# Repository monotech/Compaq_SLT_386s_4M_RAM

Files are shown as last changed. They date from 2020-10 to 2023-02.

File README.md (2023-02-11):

# Compaq SLT 386s/20 4MiB RAM Module

Can be used alongside original modules.

The DRAM chips are obsolete and need to be purchased from the grey market.

The example part numbers below are just examples. There are many compatible chips from different brands with quite different part numbers. Compare datasheets.

Original modules used 80ns chips, so acquire chips that are 80ns or faster. I used 60ns just fine. Beware of fake/bad parts.

It's best to order with ENIG surface finish rather than HASL. If you'll be replugging it over a hundred times, selective 30u" hard-gold plating is recommended.

## Bill of materials
Designator|Part
---|---
U1-2,U4-5,U7-8,U10-11|1M*4 DRAM SOJ-20(26-size) or TSOP-II such as HY514400ALJ-60
U3,U6,U9,U12|1M*1 DRAM SOJ-20(26-size) or TSOP-II such as HY531000ALJ-50
U13-14|74AHC541 TSSOP-20
C1|10uF 0805
C2-9|100nF 0603
R1-14|33 ohm 0603

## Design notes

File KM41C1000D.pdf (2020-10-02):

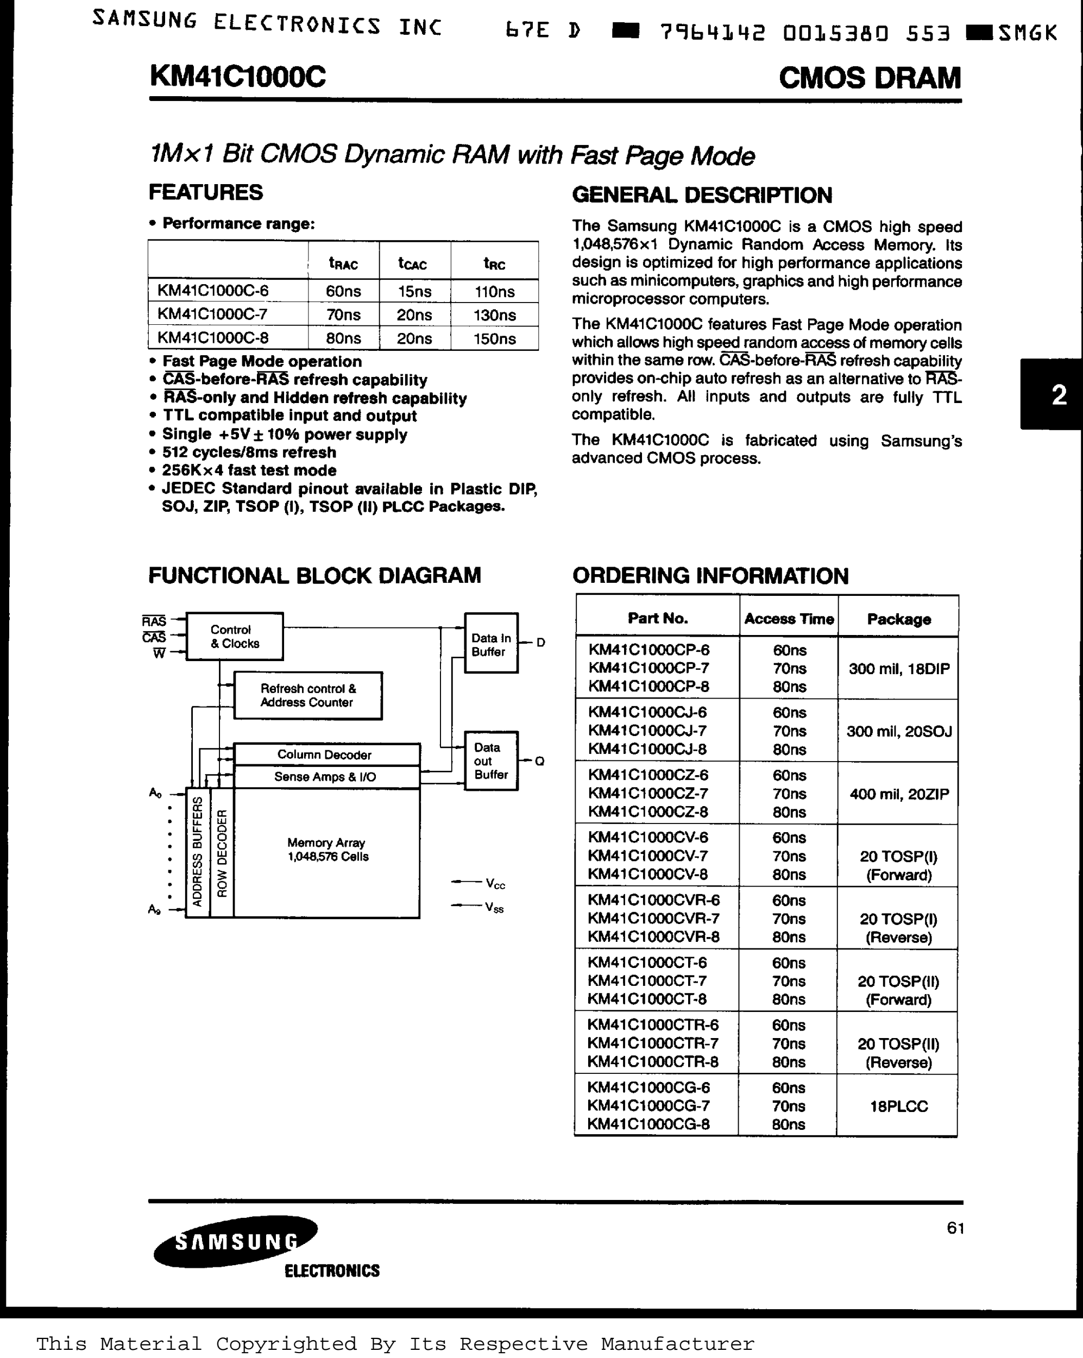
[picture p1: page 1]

This Material Copyrighted By Its Respective Manufacturer

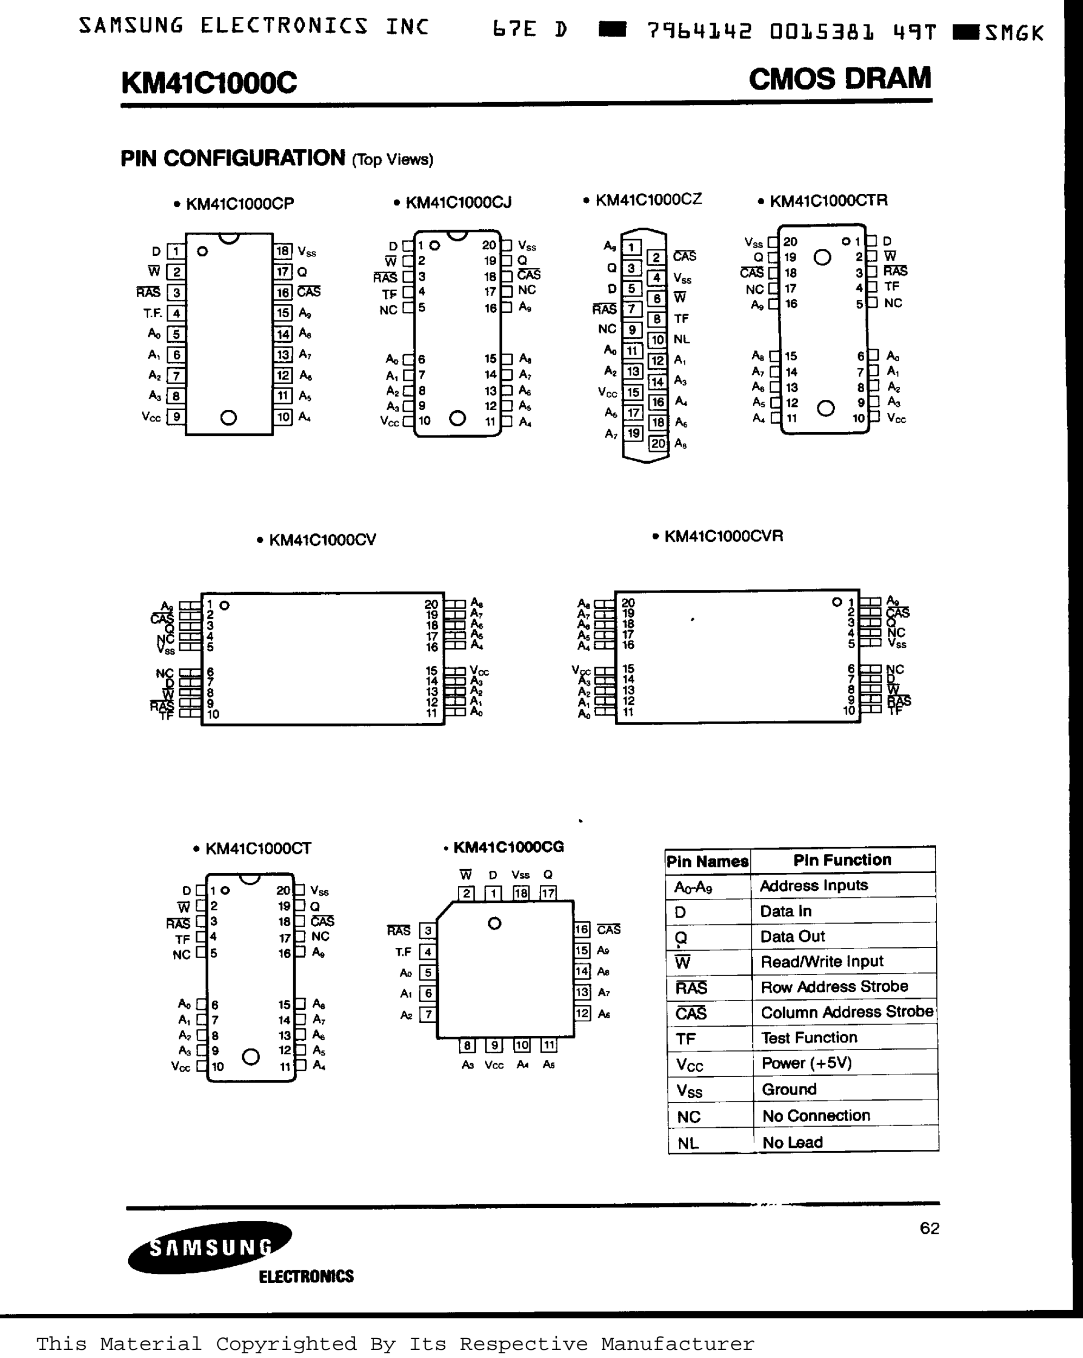
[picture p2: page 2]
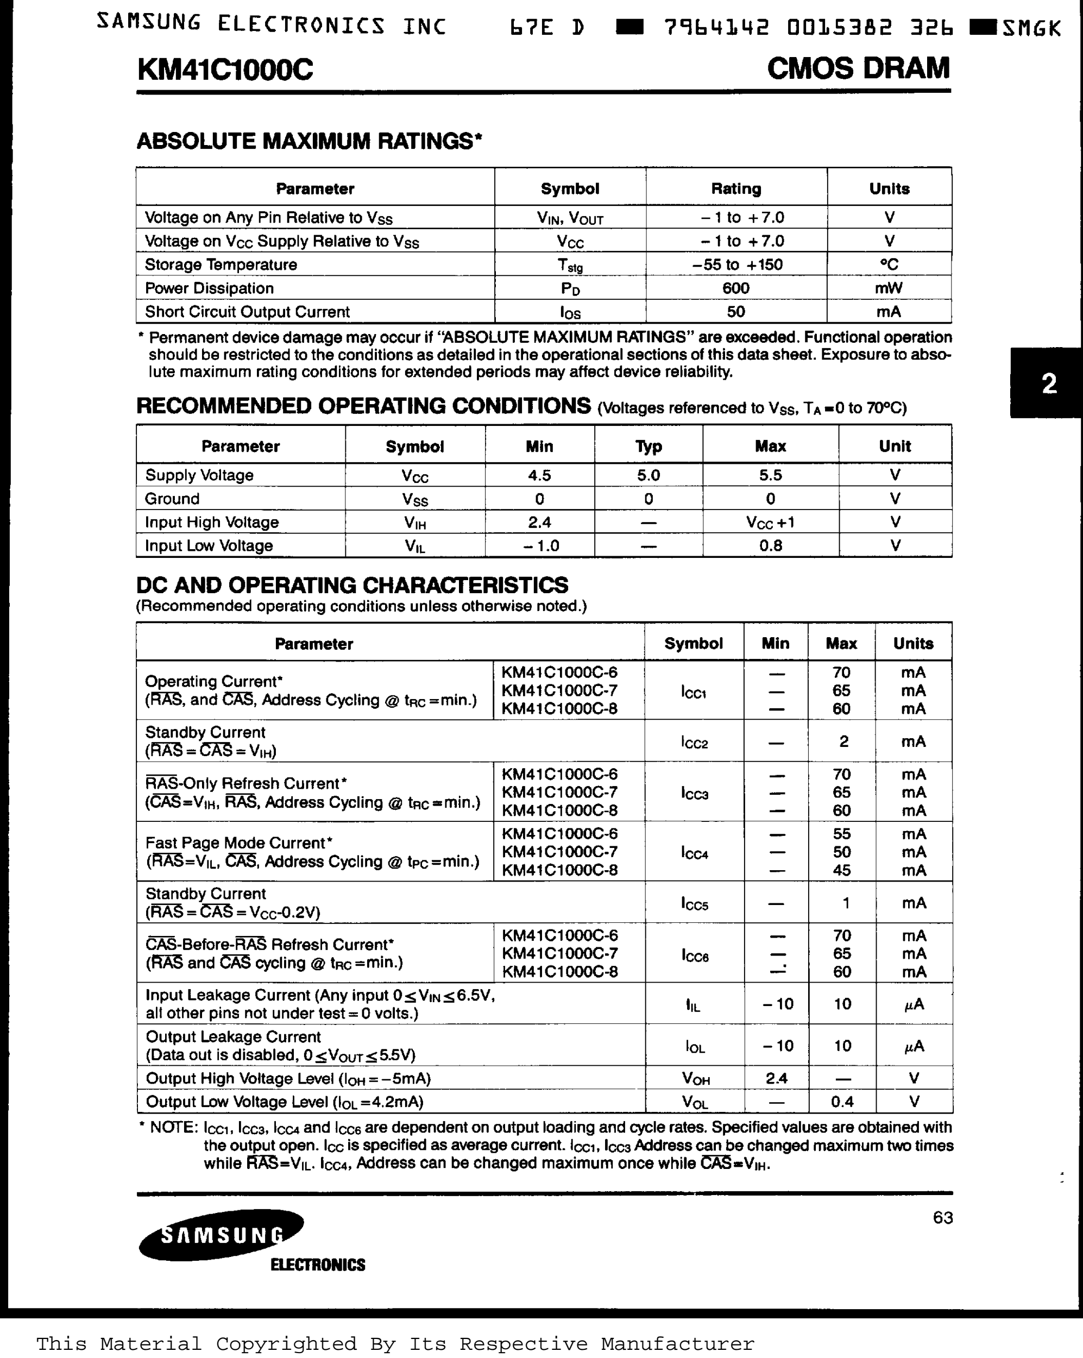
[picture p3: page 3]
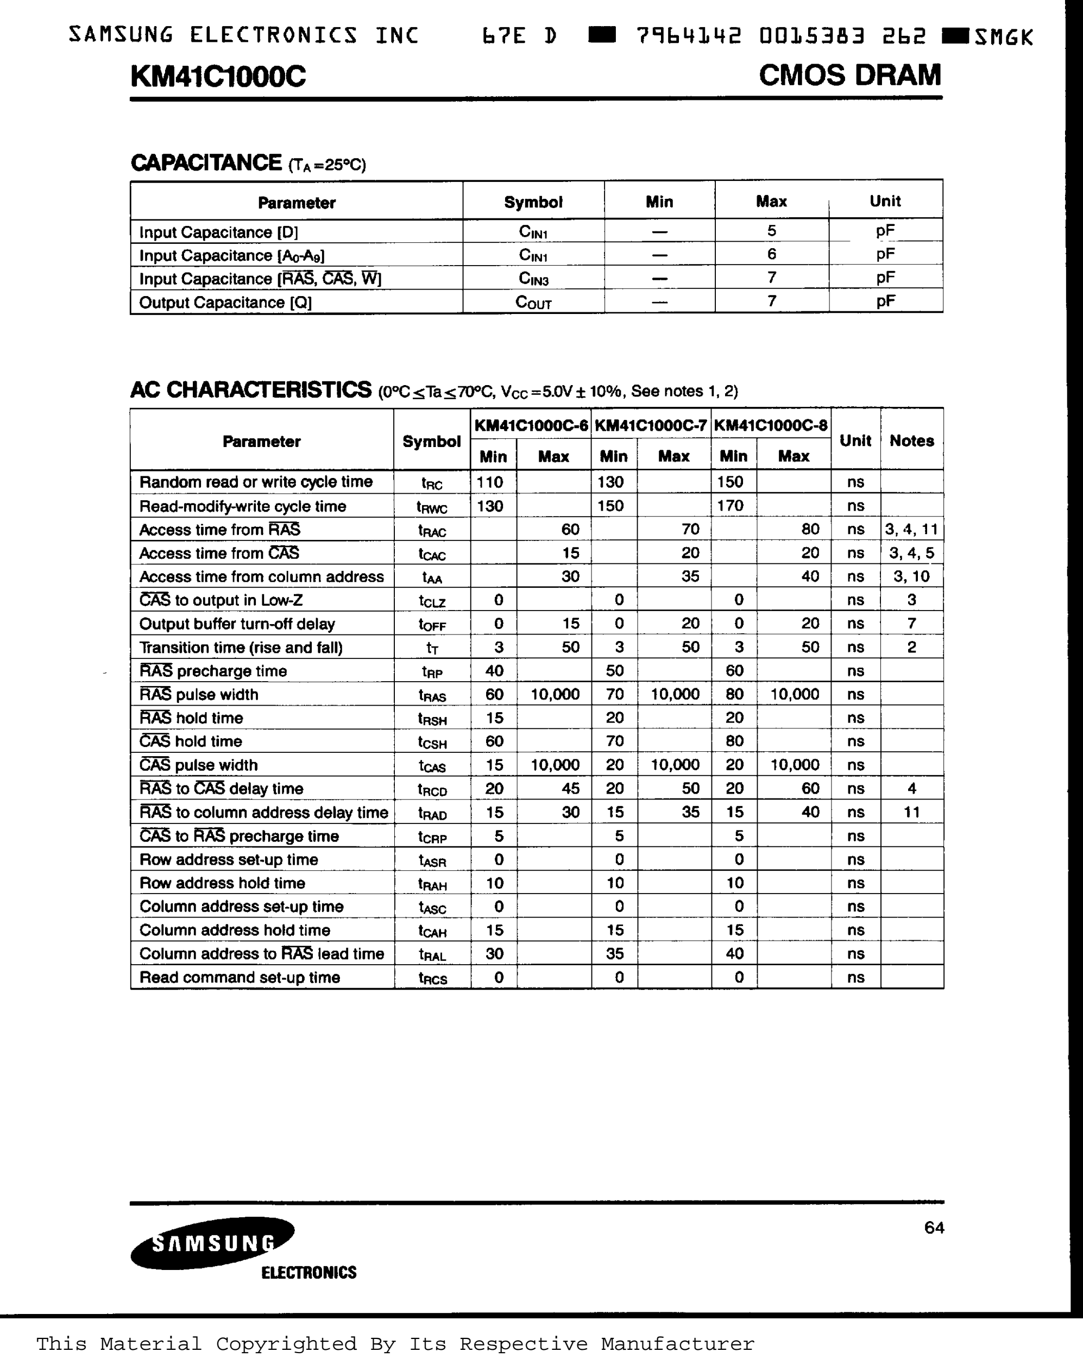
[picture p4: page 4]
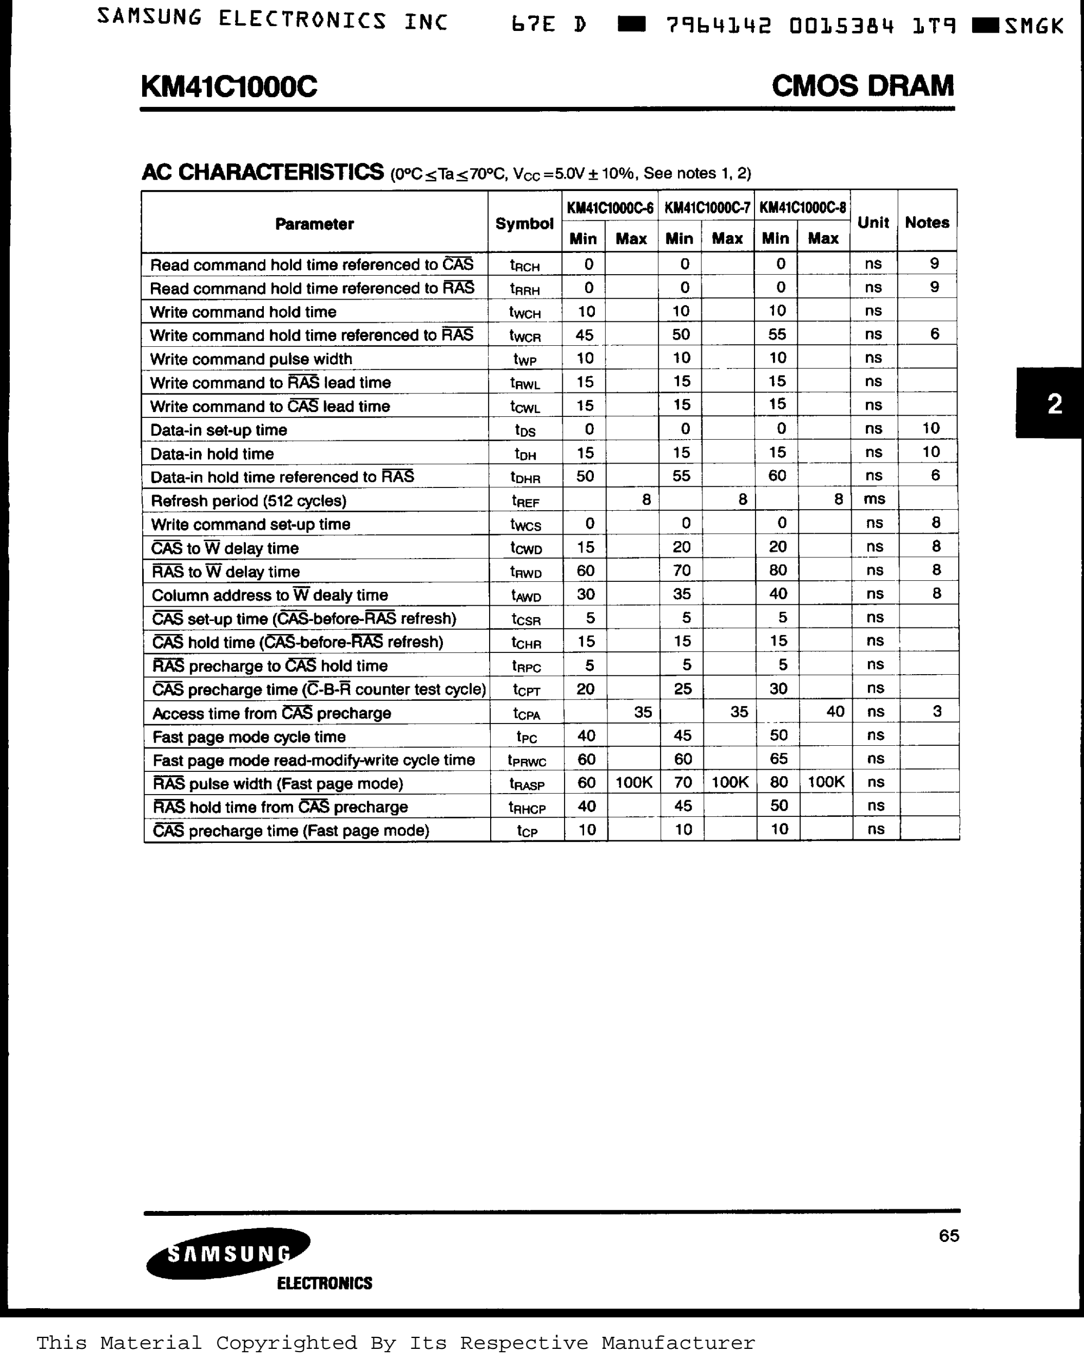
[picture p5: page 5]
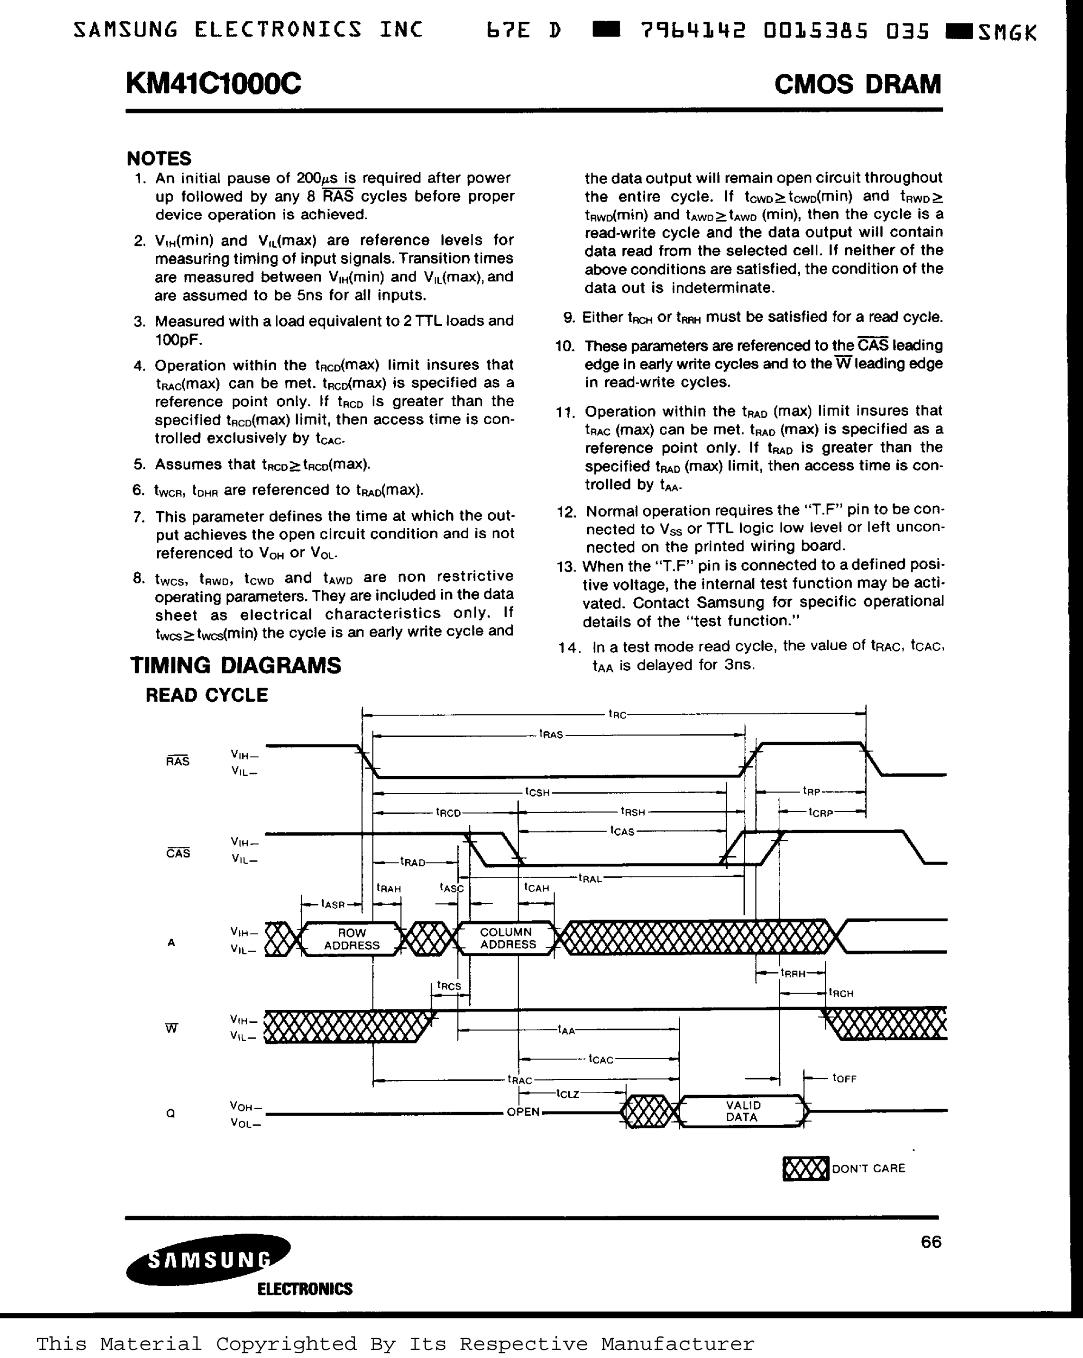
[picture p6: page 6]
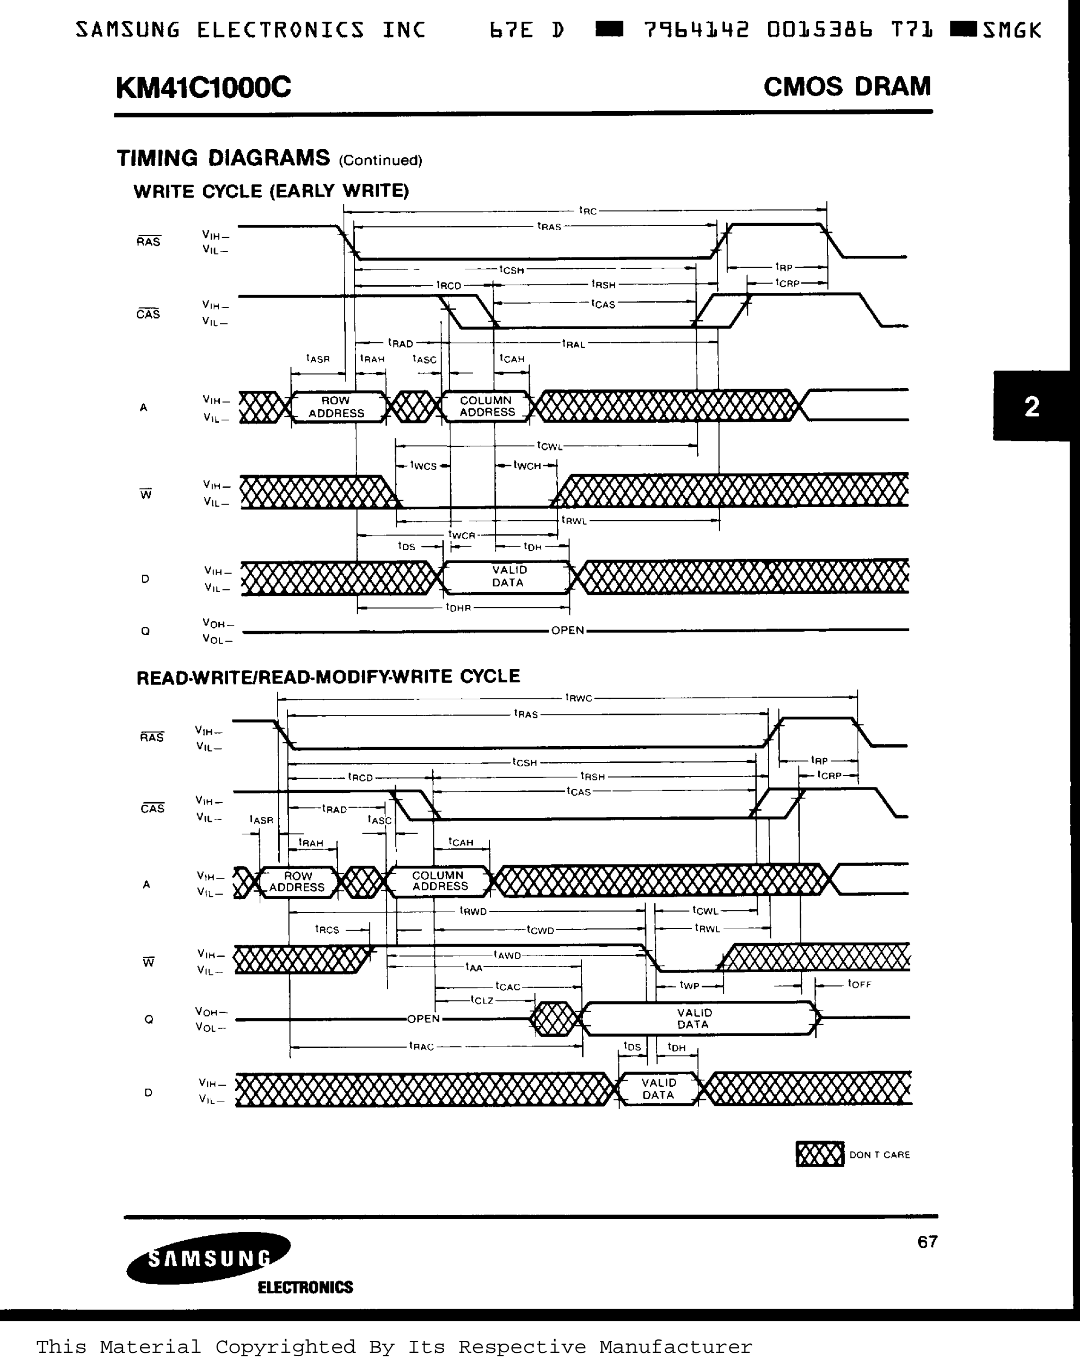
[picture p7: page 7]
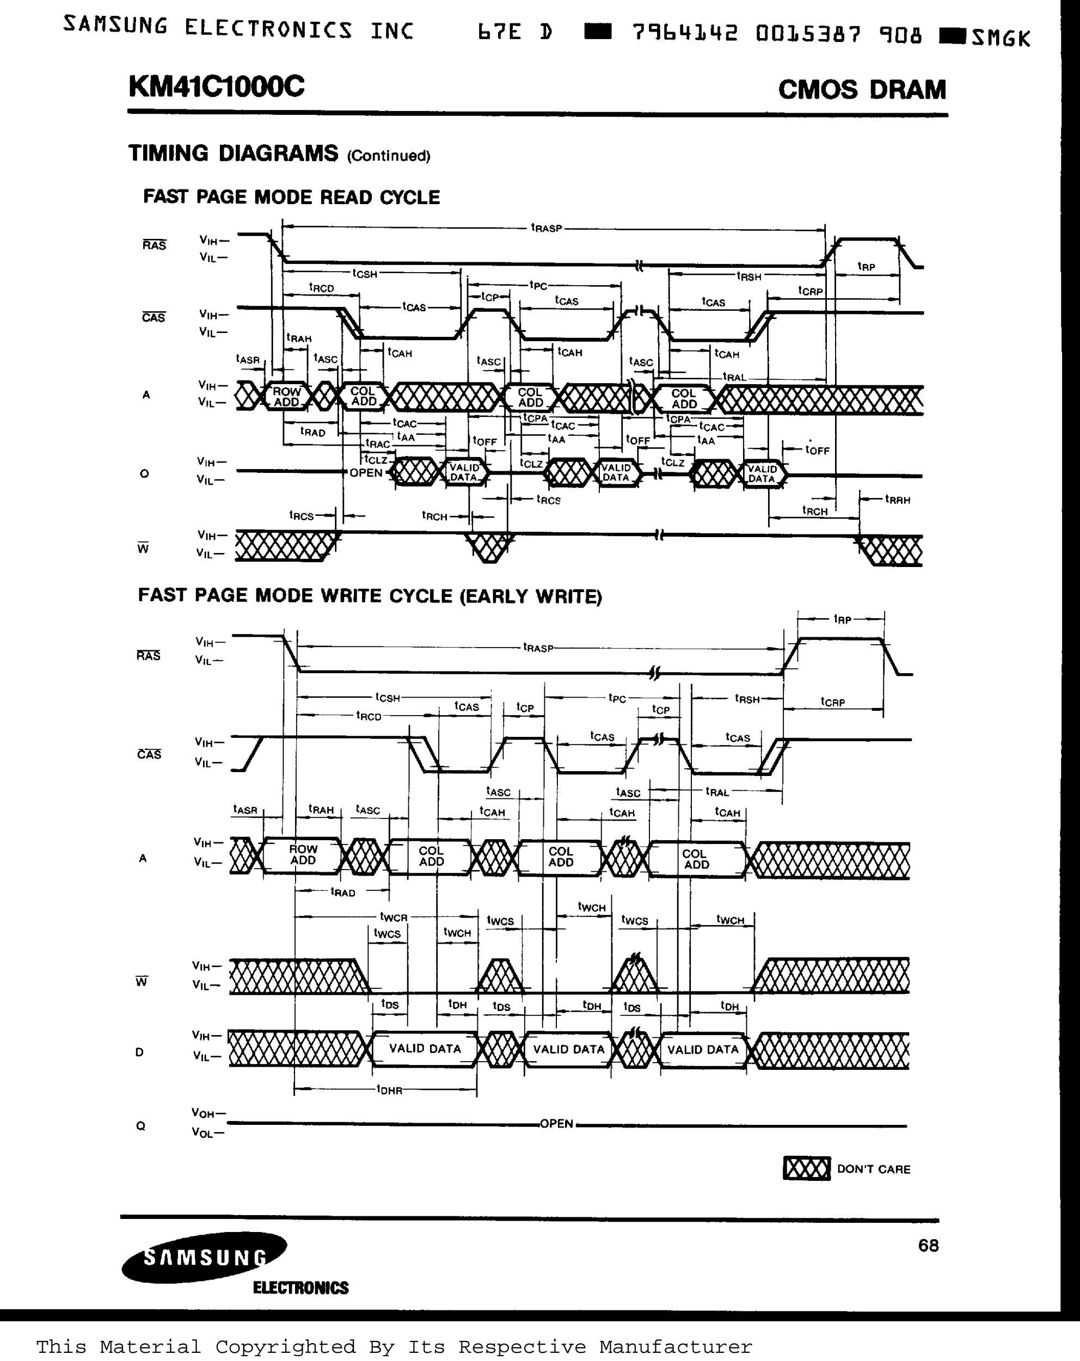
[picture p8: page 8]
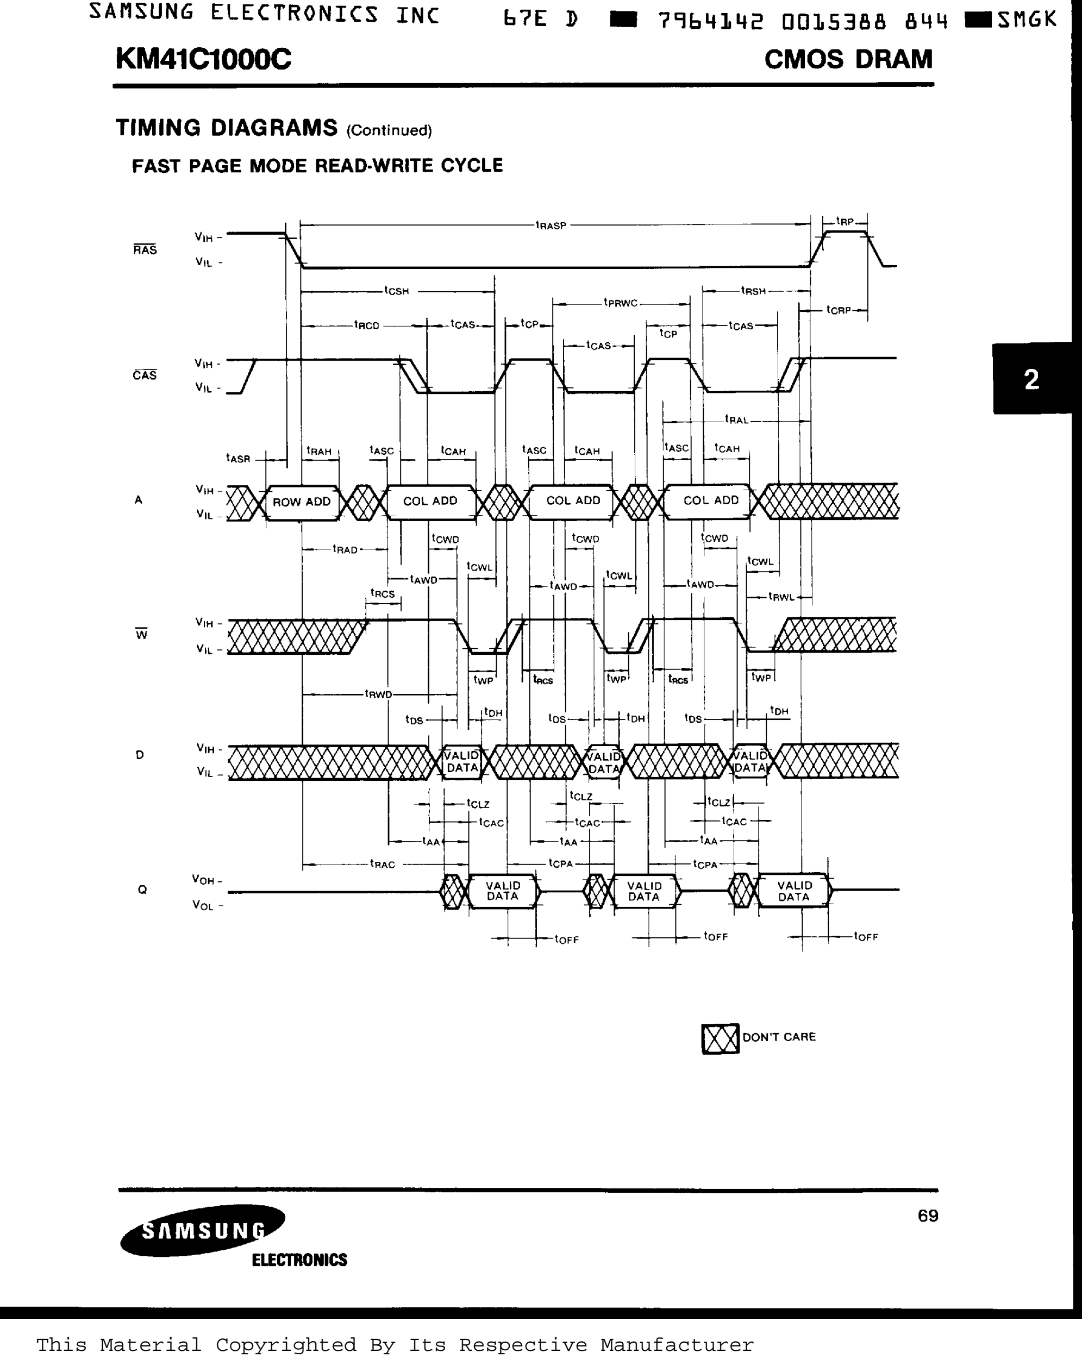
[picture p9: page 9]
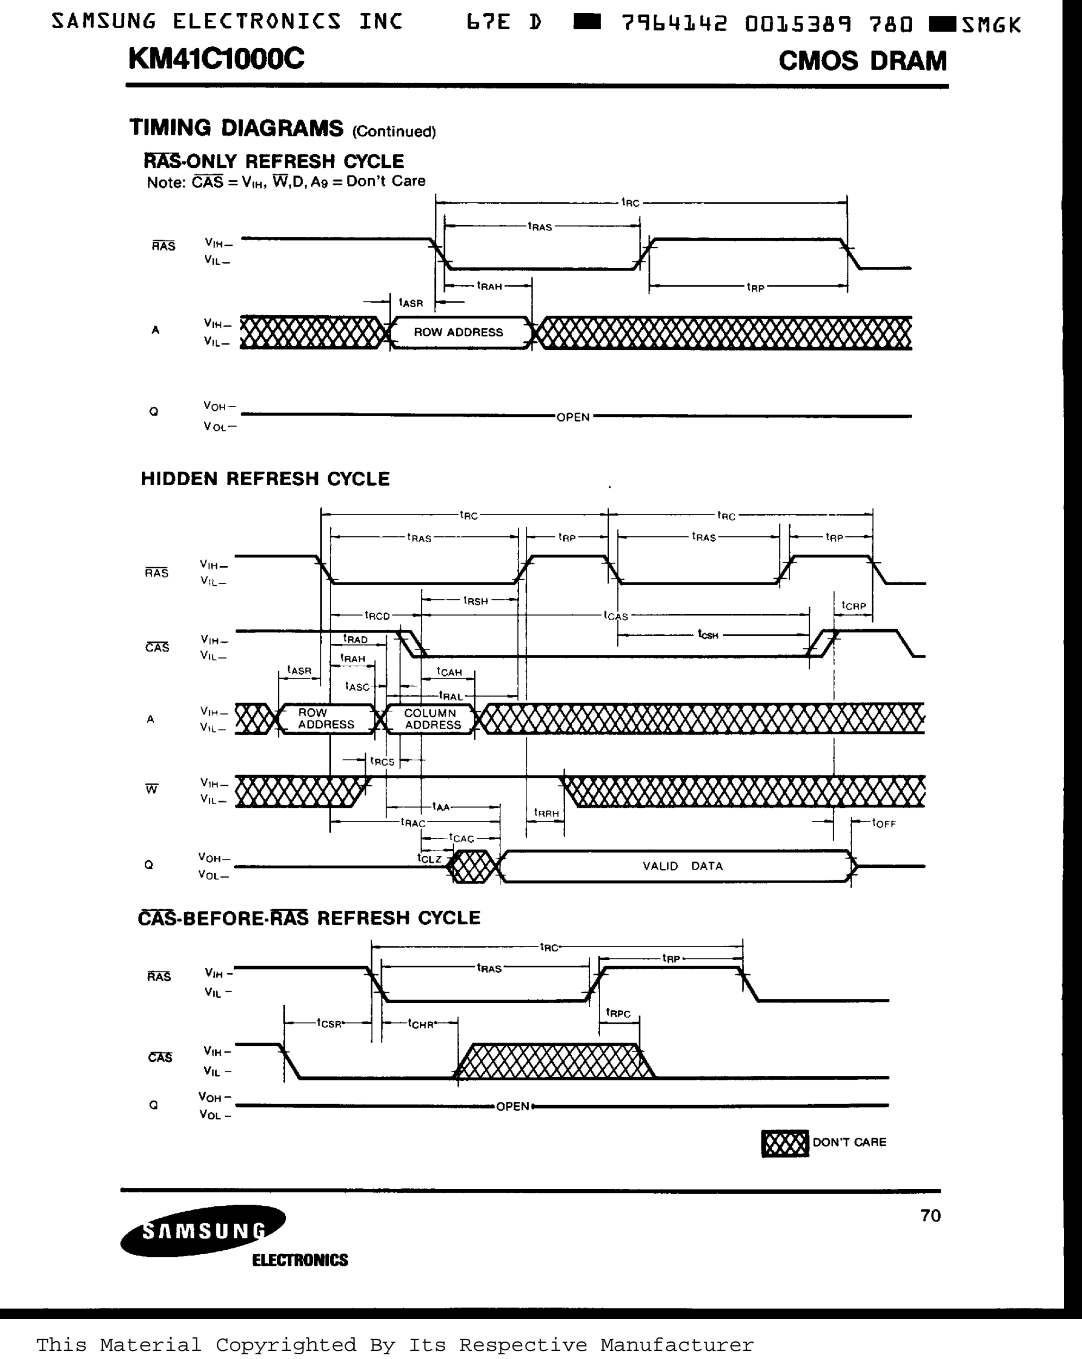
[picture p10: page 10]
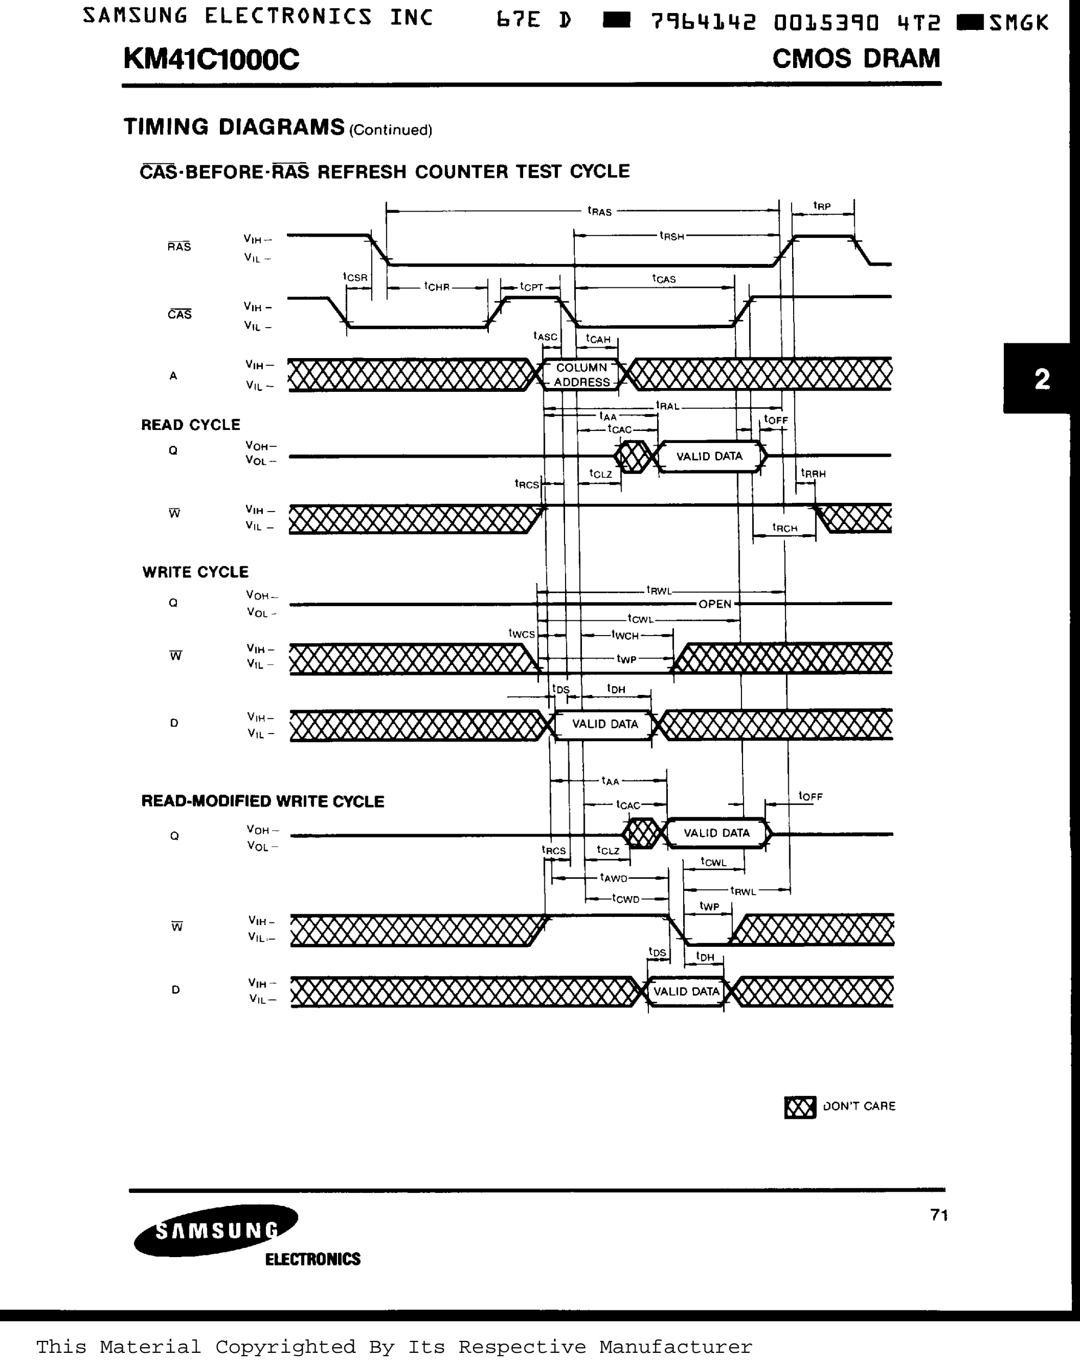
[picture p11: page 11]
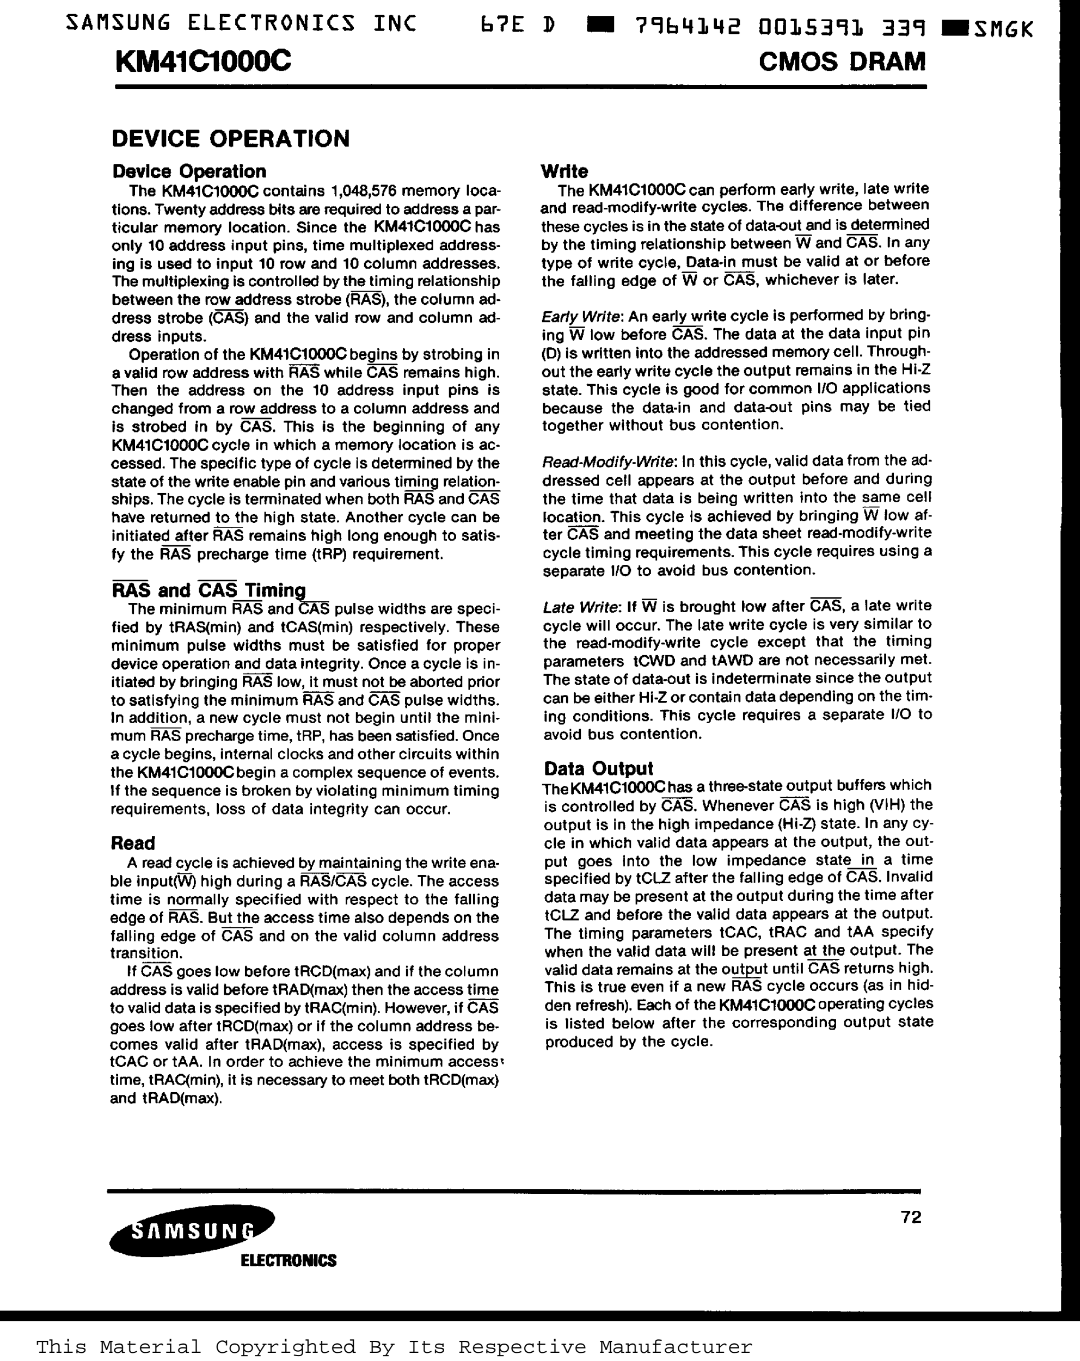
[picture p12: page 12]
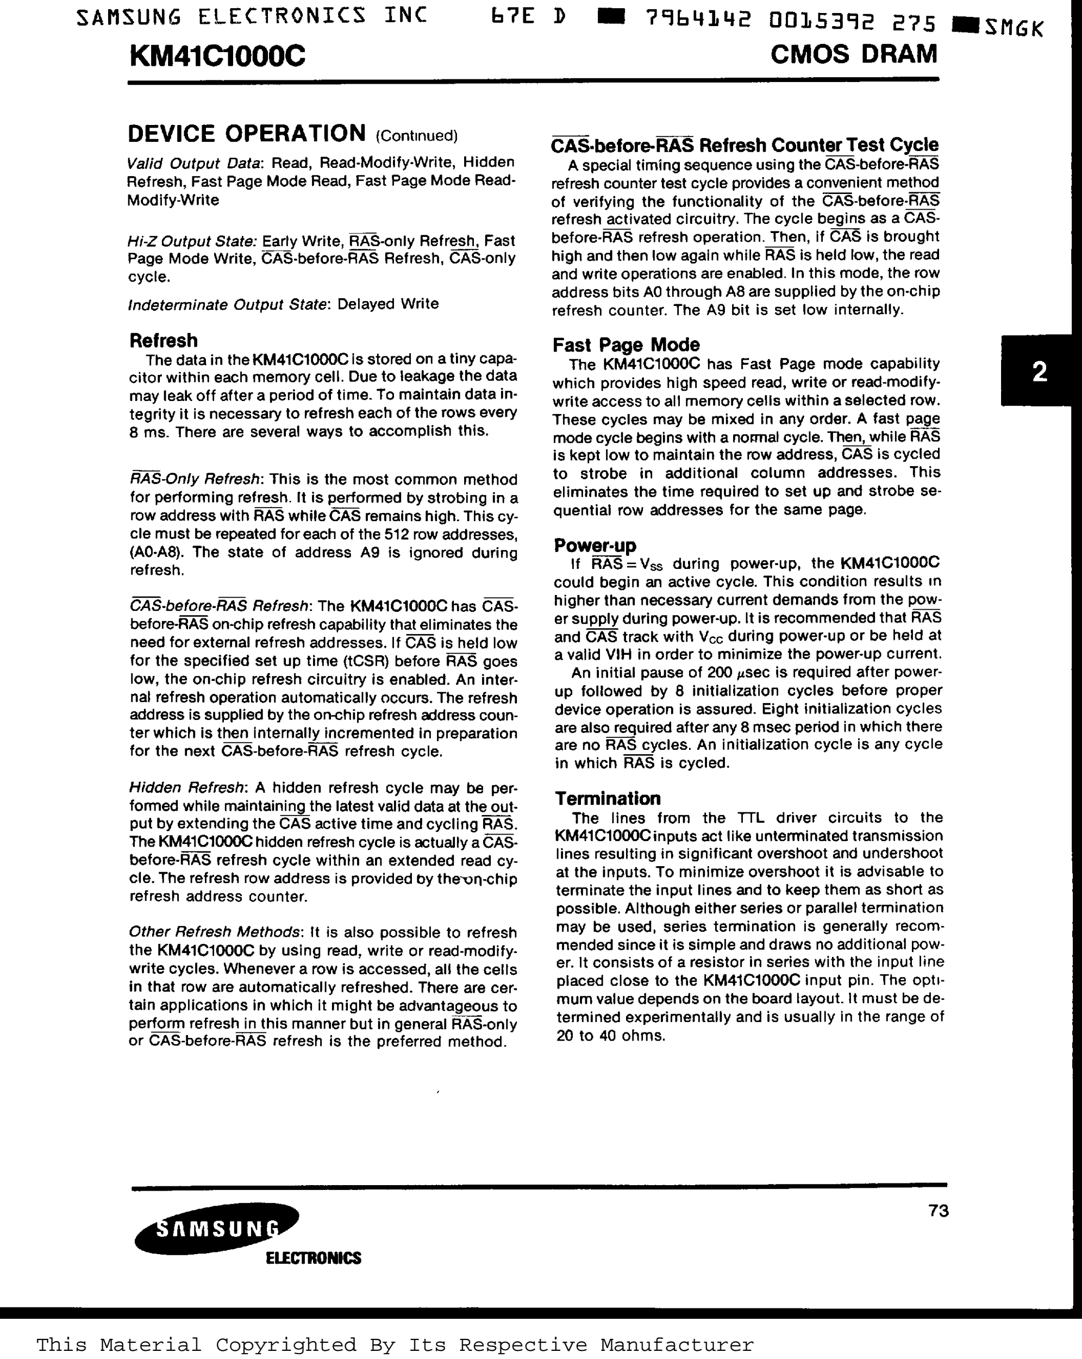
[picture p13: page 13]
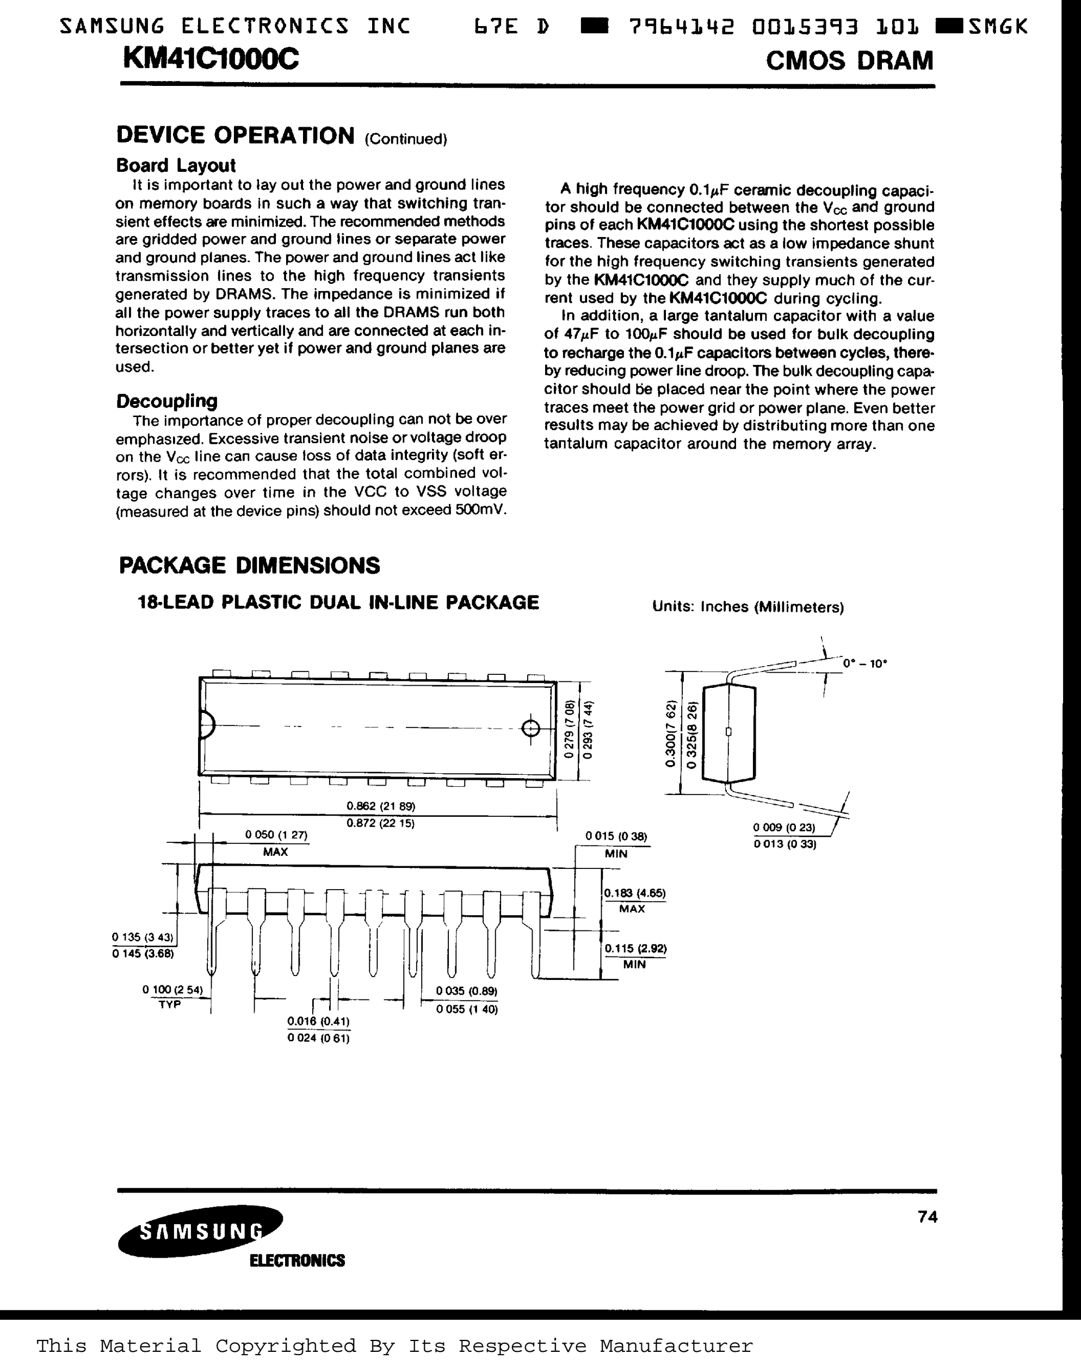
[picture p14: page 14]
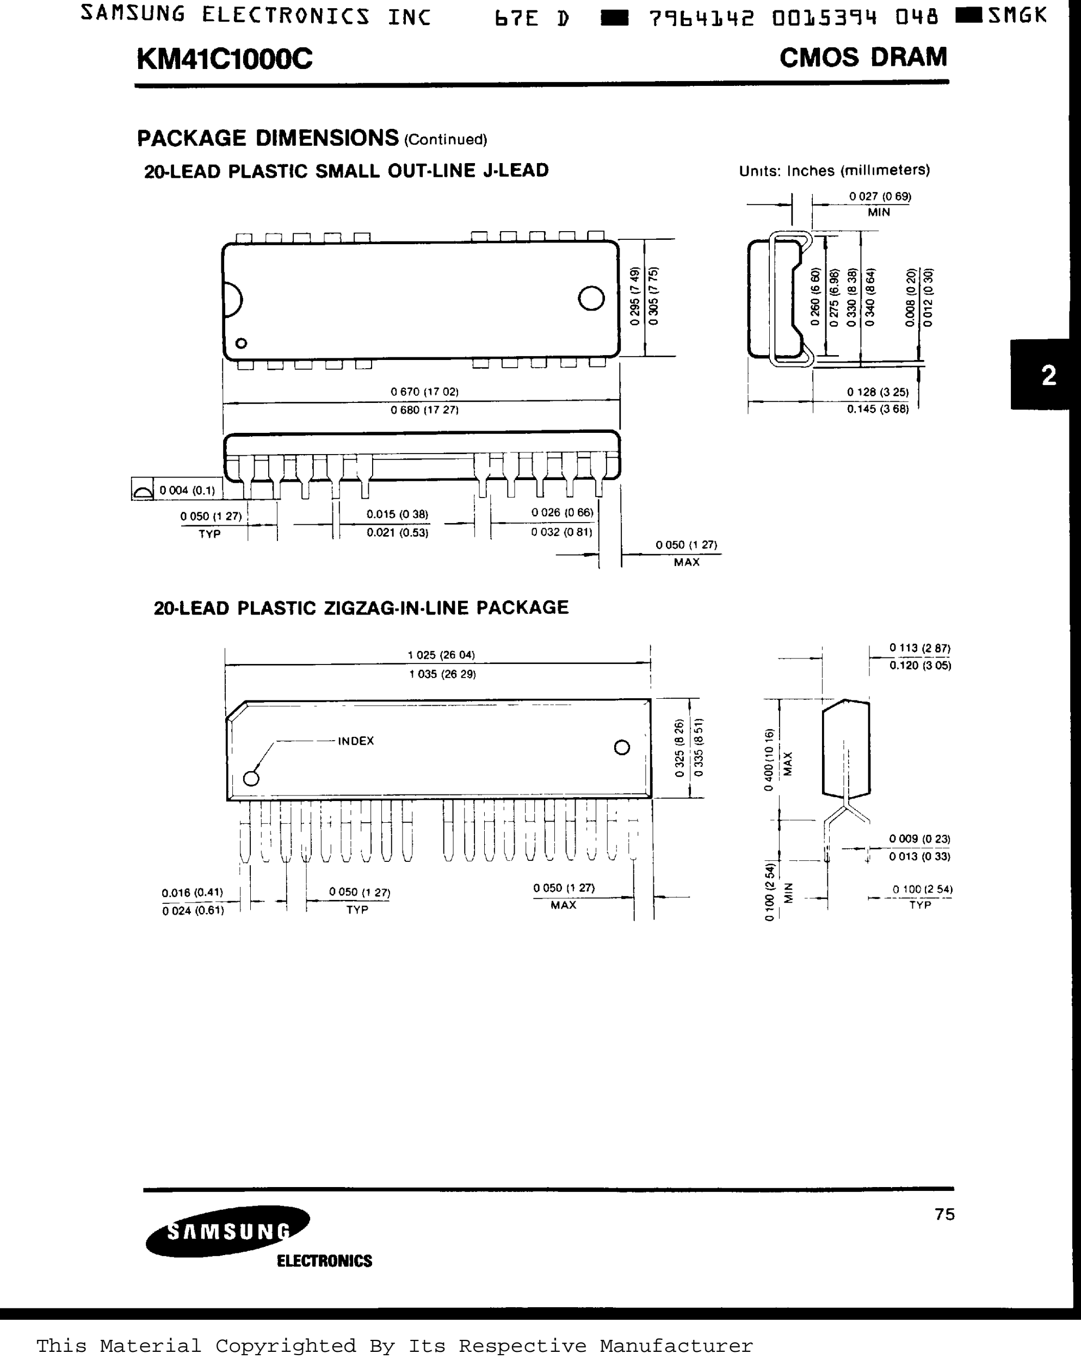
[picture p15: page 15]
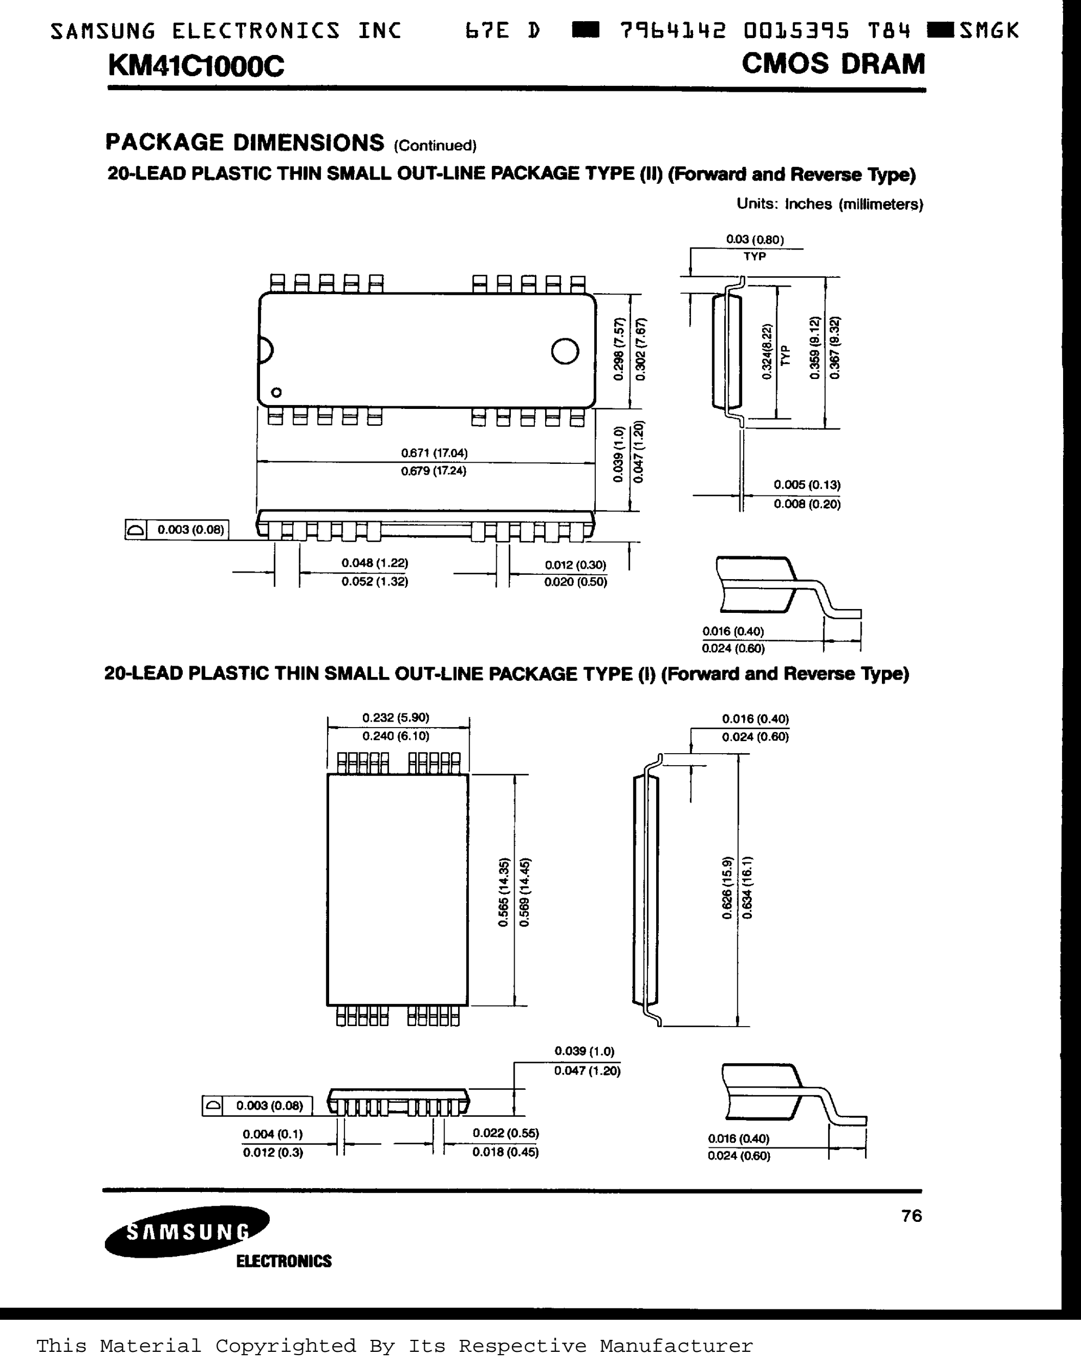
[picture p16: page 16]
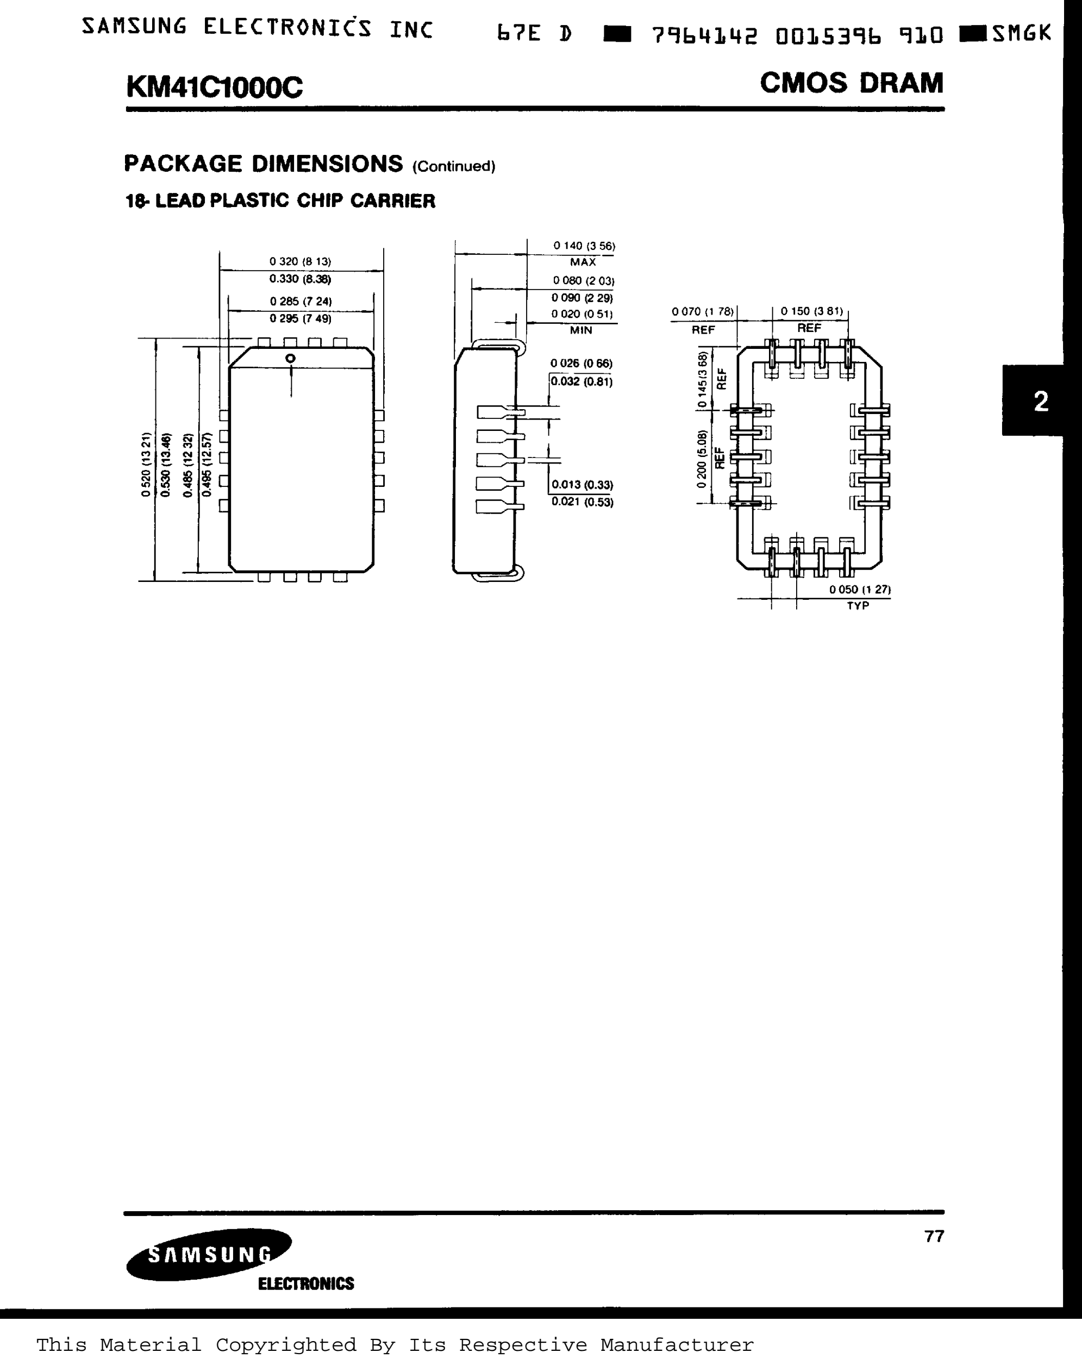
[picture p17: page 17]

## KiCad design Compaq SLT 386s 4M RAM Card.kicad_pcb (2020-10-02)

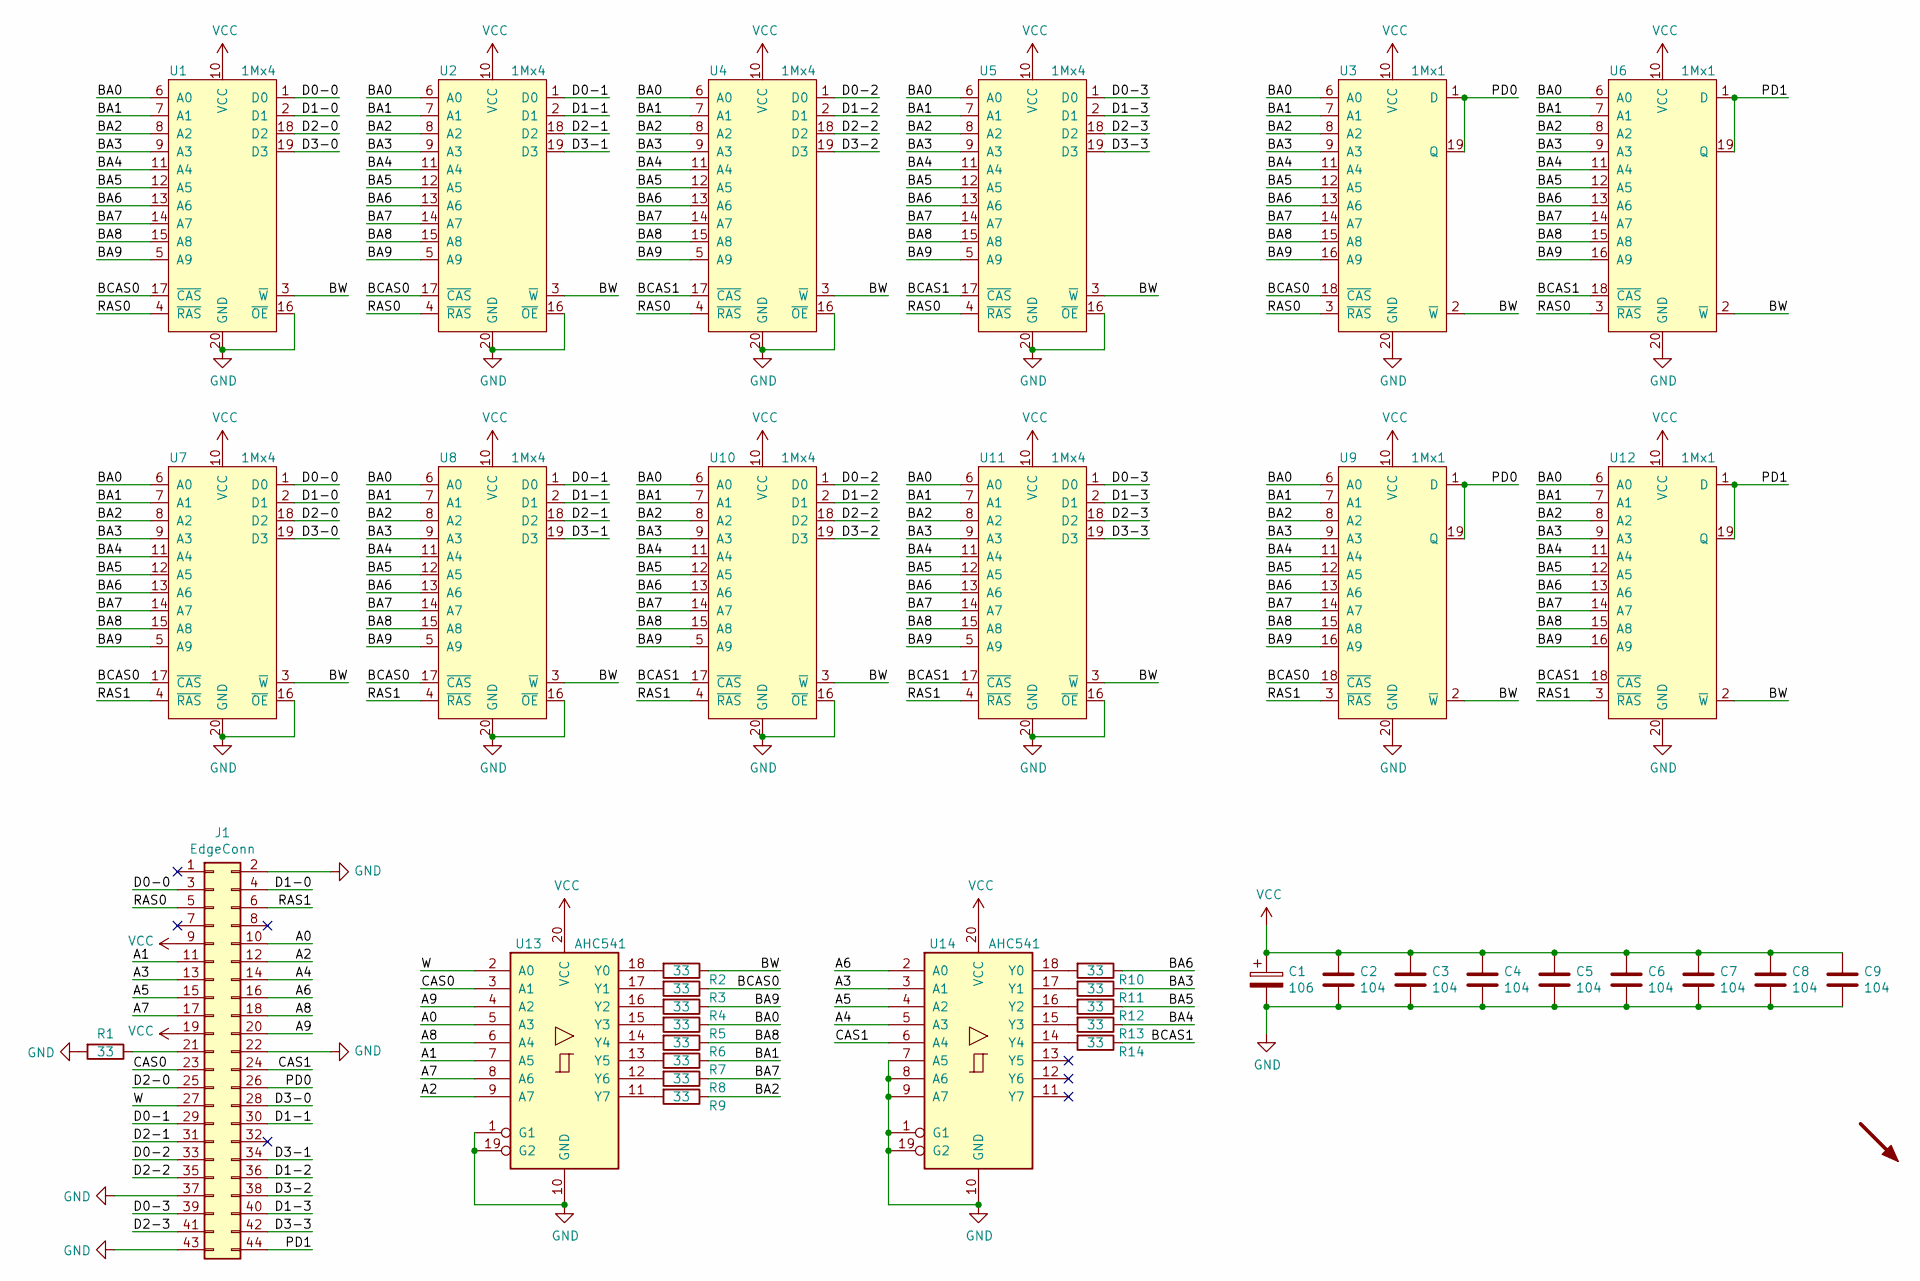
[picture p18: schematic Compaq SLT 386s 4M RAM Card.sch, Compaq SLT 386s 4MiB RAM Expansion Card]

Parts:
C1: 106; C_0805_2012Metric
C2, C3, C4, C5, C6, C7, C8, C9: 104; C_0603_1608Metric
J1: EdgeConn; Compaq_SLT386_RAM
LOGO1: LOGO; Monotech Logo 12mm
R1, R2, R3, R4, R5, R6, R7, R8, R9, R10, R11, R12, R13, R14: 33; R_0603_1608Metric
U1, U2, U4, U5, U7, U8, U10, U11: 1Mx4; TSOP-II_or_SOJ-26-20
U3, U6, U9, U12: 1Mx1; TSOP-II_or_SOJ-26-20
U13, U14: AHC541; TSSOP-20_4.4x6.5mm_P0.65mm

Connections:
/A0: J1.10, U13.5 (A3)
/A1: J1.11, U13.7 (A5)
/A2: J1.12, U13.9 (A7)
/A3: J1.13, U14.3 (A1)
/A4: J1.14, U14.5 (A3)
/A5: J1.15, U14.4 (A2)
/A6: J1.16, U14.2 (A0)
/A7: J1.17, U13.8 (A6)
/A8: J1.18, U13.6 (A4)
/A9: J1.20, U13.4 (A2)
/BA0: R5.1, U1.6 (A0), U2.6 (A0), U3.6 (A0), U4.6 (A0), U5.6 (A0), U6.6 (A0), U7.6 (A0), U8.6 (A0), U9.6 (A0), U10.6 (A0), U11.6 (A0), U12.6 (A0)
/BA1: R7.1, U1.7 (A1), U2.7 (A1), U3.7 (A1), U4.7 (A1), U5.7 (A1), U6.7 (A1), U7.7 (A1), U8.7 (A1), U9.7 (A1), U10.7 (A1), U11.7 (A1), U12.7 (A1)
/BA2: R9.1, U1.8 (A2), U2.8 (A2), U3.8 (A2), U4.8 (A2), U5.8 (A2), U6.8 (A2), U7.8 (A2), U8.8 (A2), U9.8 (A2), U10.8 (A2), U11.8 (A2), U12.8 (A2)
/BA3: R11.1, U1.9 (A3), U2.9 (A3), U3.9 (A3), U4.9 (A3), U5.9 (A3), U6.9 (A3), U7.9 (A3), U8.9 (A3), U9.9 (A3), U10.9 (A3), U11.9 (A3), U12.9 (A3)
/BA4: R13.1, U1.11 (A4), U2.11 (A4), U3.11 (A4), U4.11 (A4), U5.11 (A4), U6.11 (A4), U7.11 (A4), U8.11 (A4), U9.11 (A4), U10.11 (A4), U11.11 (A4), U12.11 (A4)
/BA5: R12.1, U1.12 (A5), U2.12 (A5), U3.12 (A5), U4.12 (A5), U5.12 (A5), U6.12 (A5), U7.12 (A5), U8.12 (A5), U9.12 (A5), U10.12 (A5), U11.12 (A5), U12.12 (A5)
/BA6: R10.1, U1.13 (A6), U2.13 (A6), U3.13 (A6), U4.13 (A6), U5.13 (A6), U6.13 (A6), U7.13 (A6), U8.13 (A6), U9.13 (A6), U10.13 (A6), U11.13 (A6), U12.13 (A6)
/BA7: R8.1, U1.14 (A7), U2.14 (A7), U3.14 (A7), U4.14 (A7), U5.14 (A7), U6.14 (A7), U7.14 (A7), U8.14 (A7), U9.14 (A7), U10.14 (A7), U11.14 (A7), U12.14 (A7)
/BA8: R6.1, U1.15 (A8), U2.15 (A8), U3.15 (A8), U4.15 (A8), U5.15 (A8), U6.15 (A8), U7.15 (A8), U8.15 (A8), U9.15 (A8), U10.15 (A8), U11.15 (A8), U12.15 (A8)
/BA9: R4.1, U1.5 (A9), U2.5 (A9), U3.16 (A9), U4.5 (A9), U5.5 (A9), U6.16 (A9), U7.5 (A9), U8.5 (A9), U9.16 (A9), U10.5 (A9), U11.5 (A9), U12.16 (A9)
/BCAS0: R3.1, U1.17 (~CAS), U2.17 (~CAS), U3.18 (~CAS), U7.17 (~CAS), U8.17 (~CAS), U9.18 (~CAS)
/BCAS1: R14.1, U4.17 (~CAS), U5.17 (~CAS), U6.18 (~CAS), U10.17 (~CAS), U11.17 (~CAS), U12.18 (~CAS)
/BW: R2.1, U1.3 (~W), U2.3 (~W), U3.2 (~W), U4.3 (~W), U5.3 (~W), U6.2 (~W), U7.3 (~W), U8.3 (~W), U9.2 (~W), U10.3 (~W), U11.3 (~W), U12.2 (~W)
/CAS0: J1.23, U13.3 (A1)
/CAS1: J1.24, U14.6 (A4)
/D0-0: J1.3, U1.1 (D0), U7.1 (D0)
/D0-1: J1.29, U2.1 (D0), U8.1 (D0)
/D0-2: J1.33, U4.1 (D0), U10.1 (D0)
/D0-3: J1.39, U5.1 (D0), U11.1 (D0)
/D1-0: J1.4, U1.2 (D1), U7.2 (D1)
/D1-1: J1.30, U2.2 (D1), U8.2 (D1)
/D1-2: J1.36, U4.2 (D1), U10.2 (D1)
/D1-3: J1.40, U5.2 (D1), U11.2 (D1)
/D2-0: J1.25, U1.18 (D2), U7.18 (D2)
/D2-1: J1.31, U2.18 (D2), U8.18 (D2)
/D2-2: J1.35, U4.18 (D2), U10.18 (D2)
/D2-3: J1.41, U5.18 (D2), U11.18 (D2)
/D3-0: J1.28, U1.19 (D3), U7.19 (D3)
/D3-1: J1.34, U2.19 (D3), U8.19 (D3)
/D3-2: J1.38, U4.19 (D3), U10.19 (D3)
/D3-3: J1.42, U5.19 (D3), U11.19 (D3)
/PD0: J1.26, U3.1 (D), U3.19 (Q), U9.1 (D), U9.19 (Q)
/PD1: J1.44, U6.1 (D), U6.19 (Q), U12.1 (D), U12.19 (Q)
/RAS0: J1.5, U1.4 (~RAS), U2.4 (~RAS), U3.3 (~RAS), U4.4 (~RAS), U5.4 (~RAS), U6.3 (~RAS)
/RAS1: J1.6, U7.4 (~RAS), U8.4 (~RAS), U9.3 (~RAS), U10.4 (~RAS), U11.4 (~RAS), U12.3 (~RAS)
/W: J1.27, U13.2 (A0)
GND: C1.2, C2.2, C3.2, C4.2, C5.2, C6.2, C7.2, C8.2, C9.2, J1.2, J1.22, J1.37, J1.43, R1.2, U1.16 (~OE), U1.20 (GND), U2.16 (~OE), U2.20 (GND), U3.20 (GND), U4.16 (~OE), U4.20 (GND), U5.16 (~OE), U5.20 (GND), U6.20 (GND), U7.16 (~OE), U7.20 (GND), U8.16 (~OE), U8.20 (GND), U9.20 (GND), U10.16 (~OE), U10.20 (GND), U11.16 (~OE), U11.20 (GND), U12.20 (GND), U13.1 (G1), U13.10 (GND), U13.19 (G2), U14.1 (G1), U14.7 (A5), U14.8 (A6), U14.9 (A7), U14.10 (GND), U14.19 (G2)
unnamed: J1.21, R1.1
unnamed: R2.2, U13.18 (Y0)
unnamed: R3.2, U13.17 (Y1)
unnamed: R4.2, U13.16 (Y2)
unnamed: R5.2, U13.15 (Y3)
unnamed: R6.2, U13.14 (Y4)
unnamed: R7.2, U13.13 (Y5)
unnamed: R8.2, U13.12 (Y6)
unnamed: R9.2, U13.11 (Y7)
unnamed: R10.2, U14.18 (Y0)
unnamed: R11.2, U14.17 (Y1)
unnamed: R12.2, U14.16 (Y2)
unnamed: R13.2, U14.15 (Y3)
unnamed: R14.2, U14.14 (Y4)
VCC: C1.1, C2.1, C3.1, C4.1, C5.1, C6.1, C7.1, C8.1, C9.1, J1.9, J1.19, U1.10 (VCC), U2.10 (VCC), U3.10 (VCC), U4.10 (VCC), U5.10 (VCC), U6.10 (VCC), U7.10 (VCC), U8.10 (VCC), U9.10 (VCC), U10.10 (VCC), U11.10 (VCC), U12.10 (VCC), U13.20 (VCC), U14.20 (VCC)

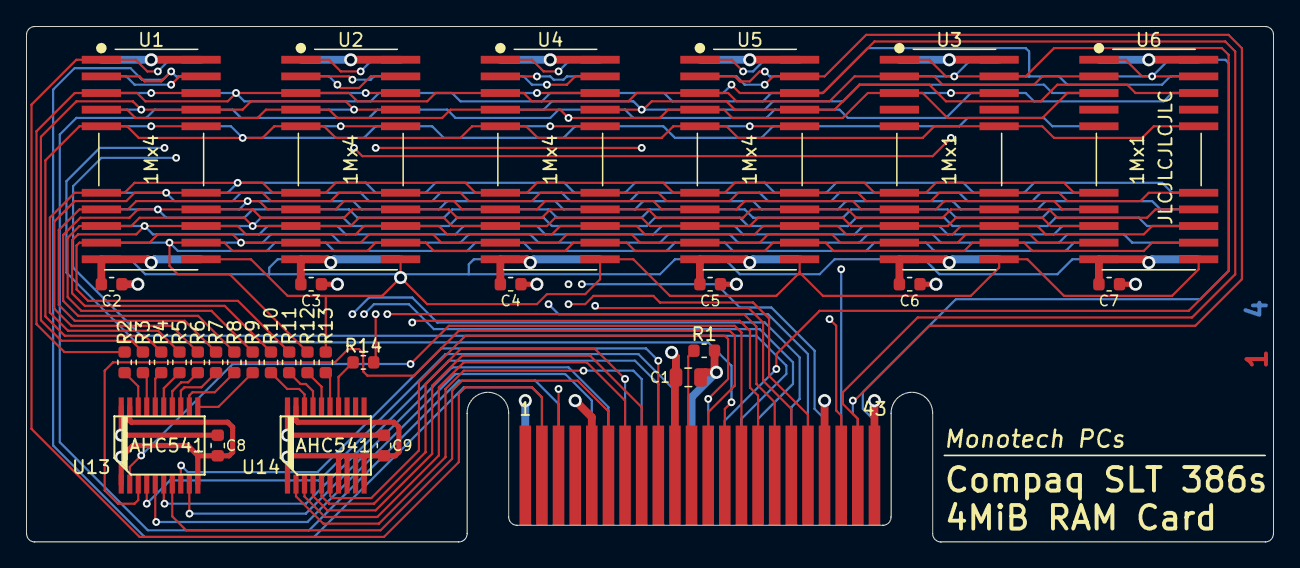
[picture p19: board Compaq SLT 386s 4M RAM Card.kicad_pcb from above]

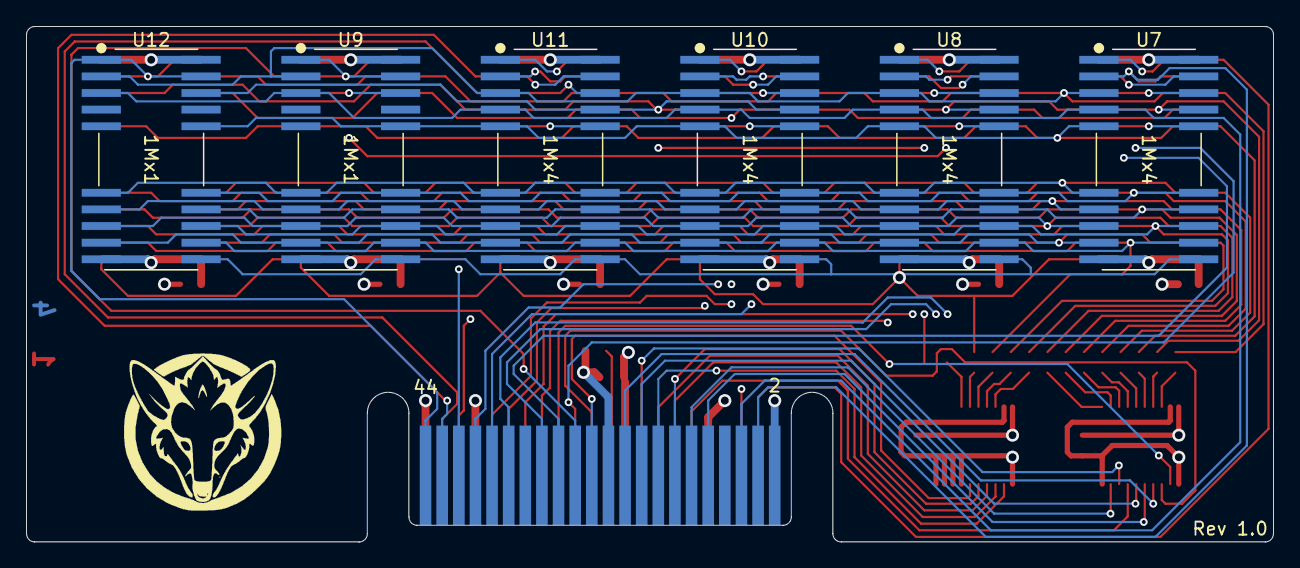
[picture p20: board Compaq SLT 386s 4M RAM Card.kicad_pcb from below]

Board: 4 copper layers, 95.2 x 39.4 mm, 39 parts (7 on the bottom side), 62 nets.
